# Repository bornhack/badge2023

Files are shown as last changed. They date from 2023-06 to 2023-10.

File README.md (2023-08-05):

# BornHack 2023 NFC Badges

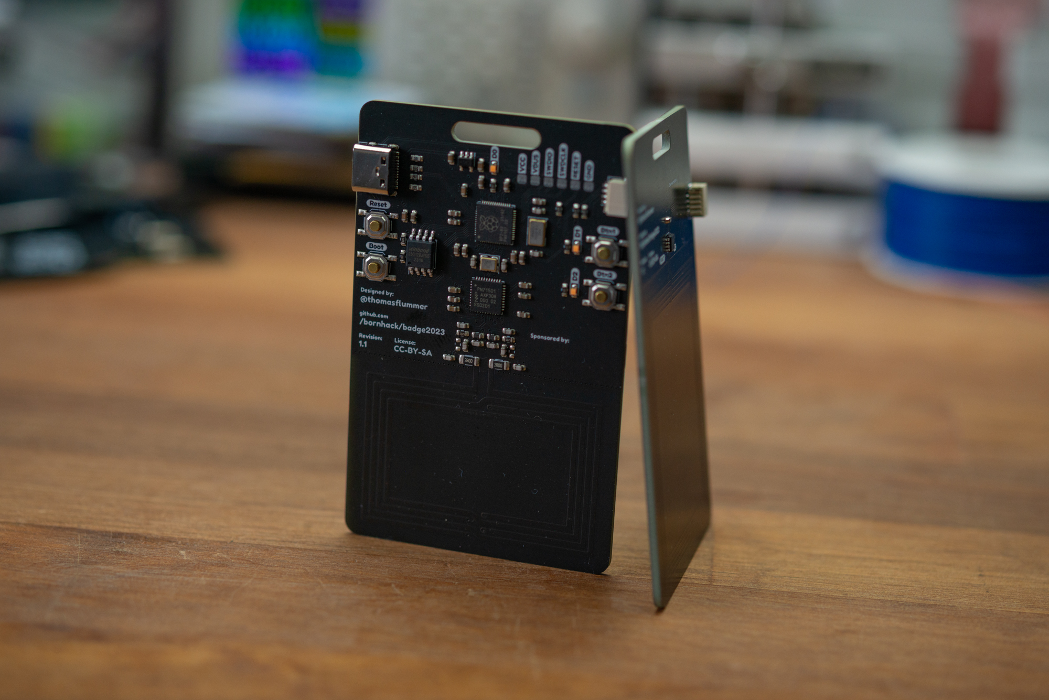
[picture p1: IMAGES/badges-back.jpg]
BornHack 2023 NFC Badges


With this years badges, we are taking a look at NFC. There will be two badges, one that is a tag (using the NXP NTAG I2C Plus chip), and another with an NFC reader (using NXP PN7150), that can also do card emulation.

The reader badge sports an RP2040 dual core Cortex M0+ microcontroller from Raspberry Pi and 16MB of Quad SPI flash for code and data files, to handle USB connection and general application control.

The reader badge will come with [CircuitPython](https://circuitpython.org/) preloaded, for a very low barrier of entry, all you need is a USB-C cable, and your favorite text editor and you're ready for NFC hacking.

## CircuitPython restore file

If you flash the board with something else and want to get back to CircuitPython:
Bring the badge into the UF2 bootloader. This is done by holding the BOOT button and pressing RESET or by holding BOOT while powering on.
The badge will then show up as a mass storage device called something like RP2-?. This is the built in bootloader.
Then simply copy [firmware.uf2](https://github.com/bornhack/badge2023/raw/main/firmware.uf2) from the root of this repository.
The badge will reboot, and you are then back to CircuitPython.

CircuitPython supported with this board is found in the [circuitpython branch](https://github.com/bornhack/badge2023/tree/circuitpython)

The original python files that was on the badge when handed out are in the [cp-init branch](https://github.com/bornhack/badge2023/tree/cp-init)

## Designed in KiCad v7

To open the project, you will need to install a recent release version or one of the nightly builds, KiCad v5 or v6 won't open this design. The [reader schematic as a PDF](https://github.com/bornhack/badge2023/raw/main/nfc_reader/nfc_reader_schematics.pdf) and the [tag schematic as a PDF](https://github.com/bornhack/badge2023/raw/main/nfc_card_emulation_large/nfc_card_emulation_large_schematics.pdf) are included for reference.

Main Components:

- [Raspberry Pi SoC RP2040 - low-cost, high-performance microcontroller device](https://www.raspberrypi.com/documentation/microcontrollers/rp2040.html)
    - [datasheet](https://datasheets.raspberrypi.com/rp2040/rp2040-datasheet.pdf)
    - [RP2040 SDK Manuel](https://www.raspberrypi.com/documentation/microcontrollers/c_sdk.html#sdk-setup)
    - [RP2040 SDK git repository](https://github.com/raspberrypi/pico-sdk)
- [NXP PN7150 - High-Performance NFC Controller with Integrated Firmware](https://www.nxp.com/products/rfid-nfc/nfc-hf/nfc-readers/high-performance-nfc-controller-with-integrated-firmware-for-smart-devices:PN7150)
    - [Datasheet](https://www.nxp.com/docs/en/data-sheet/PN7150.pdf)
    - [User Manual](https://www.nxp.com/docs/en/user-guide/UM10936.pdf)
- [W25Q128JV - 128M-bit Serial Flash Memory with uniform 4KB sectors and Dual/Quad SPI](https://www.winbond.com/hq/product/code-storage-flash-memory/serial-nor-flash/?__locale=en&partNo=W25Q128JV)
    - [datasheet](https://www.winbond.com/hq/support/documentation/downloadV2022.jsp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)
- [NXP NT3H2211W0FTT - NTAG I2C plus 2K, NFC Forum Type 2 Tag with I2C interface](https://www.nxp.com/part/NT3H2211W0FTT#/)
    - [datasheet](https://www.nxp.com/docs/en/data-sheet/NT3H2111_2211.pdf)

## Projects running on the badge

Feel free to submit a PR adding on to this list with your project that runs on the badge.

- _project name and link to more info_

## License

The hardware design of the `main` branch of this repository is released under the following license:

* the "Creative Commons Attribution-ShareAlike 4.0 International License"
  (CC BY-SA 4.0) full text of this license is included in the LICENSE file
  and a copy can also be found at
  [http://creativecommons.org/licenses/by-sa/4.0/](http://creativecommons.org/licenses/by-sa/4.0/)

The CircuitPython firmware of the `circuitpython` branch is released under the MIT license with smaller dependencies under other licenses as detailed in [its LICENSE](https://github.com/bornhack/badge2023/blob/circuitpython/LICENSE) and [LICENSE_MicroPython](https://github.com/bornhack/badge2023/blob/circuitpython/LICENSE_MicroPython) files.

The Python NFC demonstration application of the `cp-init` branch is released under the MIT license as detailed in its [LICENSE file](https://github.com/bornhack/badge2023/blob/cp-init/LICENSE).

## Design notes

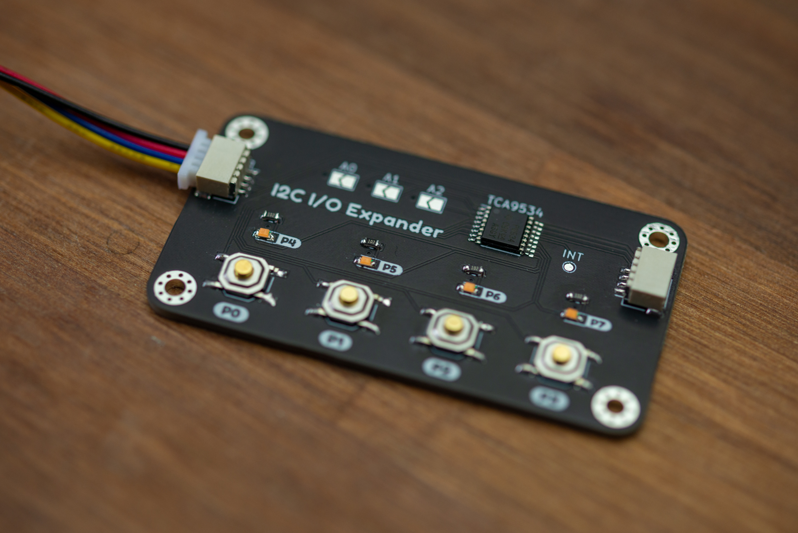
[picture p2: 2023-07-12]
IMAGES/io-expander.jpg

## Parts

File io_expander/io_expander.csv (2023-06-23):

Id | Designator | Footprint | Quantity | Designation | Supplier and ref
1 | R2,R4,R1,R3 | R_0603_1608Metric | 4 | 1k
2 | SW3,SW2,SW1,SW4 | SW_SPST_TL3342 | 4 | TS5220A
3 | J1,J2 | JST_SH_SM04B-SRSS-TB_1x04-1MP_P1.00mm_Horizontal | 2 | LCSC C145956
4 | D1,D4,D2,D3 | LED_0603_1608Metric | 4 | LED
5 | U1 | TSSOP-16_4.4x5mm_P0.65mm | 1 | TCA9534

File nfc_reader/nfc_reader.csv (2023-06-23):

Id | Designator | Footprint | Quantity | Designation | Supplier and ref
1 | R2,R1,R11,R10 | R_0603_1608Metric | 4 | 10k
2 | Y2 | Crystal_SMD_3225-4Pin_3.2x2.5mm | 1 | 27.12MHz, 10pF
3 | L2,L1 | L_0603_1608Metric | 2 | 560nH, 5%
4 | C10,C8,C14,C11,C9,C19,C13,C18,C6,C7,C4 | C_0603_1608Metric | 11 | 100nF
5 | SW2,SW7,SW6,SW1 | SW_SPST_TL3342 | 4 | TS5220A
6 | C27,C28,C29,C30 | C_0603_1608Metric | 4 | 200pF/16V, NP0, 5%
7 | C12,C5,C17 | C_0603_1608Metric | 3 | 2.2uF
8 | C23,C24 | C_0603_1608Metric | 2 | 10pF
9 | R3,R9,R4,R12,R17,R18 | R_0603_1608Metric | 6 | 1k
10 | R15,R16 | R_1206_3216Metric | 2 | 2.00R 1%
11 | C3,C2,C22,C1,C20 | C_0603_1608Metric | 5 | 1uF
12 | Y1 | Crystal_SMD_5032-4Pin_5.0x3.2mm | 1 | 12MHz, 20pF
13 | J2 | JST_SH_SM04B-SRSS-TB_1x04-1MP_P1.00mm_Horizontal | 1 | LCSC C145956
14 | R7,R8 | R_0603_1608Metric | 2 | 5.1k
15 | C31,C32 | C_0603_1608Metric | 2 | 27pF/50V, NP0, 2%
16 | C25,C26 | C_0603_1608Metric | 2 | 1nF/16V
17 | J1 | USB_C_Receptacle_XKB_U262-16XN-4BVC11 | 1 | USB_C
18 | R14,R13 | R_0603_1608Metric | 2 | 27R
19 | D0,D1,D2 | LED_0603_1608Metric | 3 | LED
20 | C16,C15 | C_0603_1608Metric | 2 | 30pF
21 | C21 | C_0603_1608Metric | 1 | 4.7uF
22 | U5 | QFN-56_EP_7x7_Pitch0.4mm | 1 | RP2040
23 | U1 | SOT-23-5 | 1 | HX9193-33GB
24 | U3 | HVQFN-40-1EP_6x6mm_P0.5mm_EP4.1x4.1mm | 1 | PN7150B0HN/C11002Y
25 | U4 | SOIC-8_5.23x5.23mm_P1.27mm | 1 | W25QXX128MBIT

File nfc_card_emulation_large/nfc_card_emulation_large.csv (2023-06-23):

Id | Designator | Footprint | Quantity | Designation | Supplier and ref
1 | J3 | JST_SH_SM04B-SRSS-TB_1x04-1MP_P1.00mm_Horizontal | 1 | LCSC C145956
2 | C33 | C_0603_1608Metric | 1 | 100nf
3 | U2 | TSSOP-8_3x3mm_P0.65mm | 1 | NT3H2211

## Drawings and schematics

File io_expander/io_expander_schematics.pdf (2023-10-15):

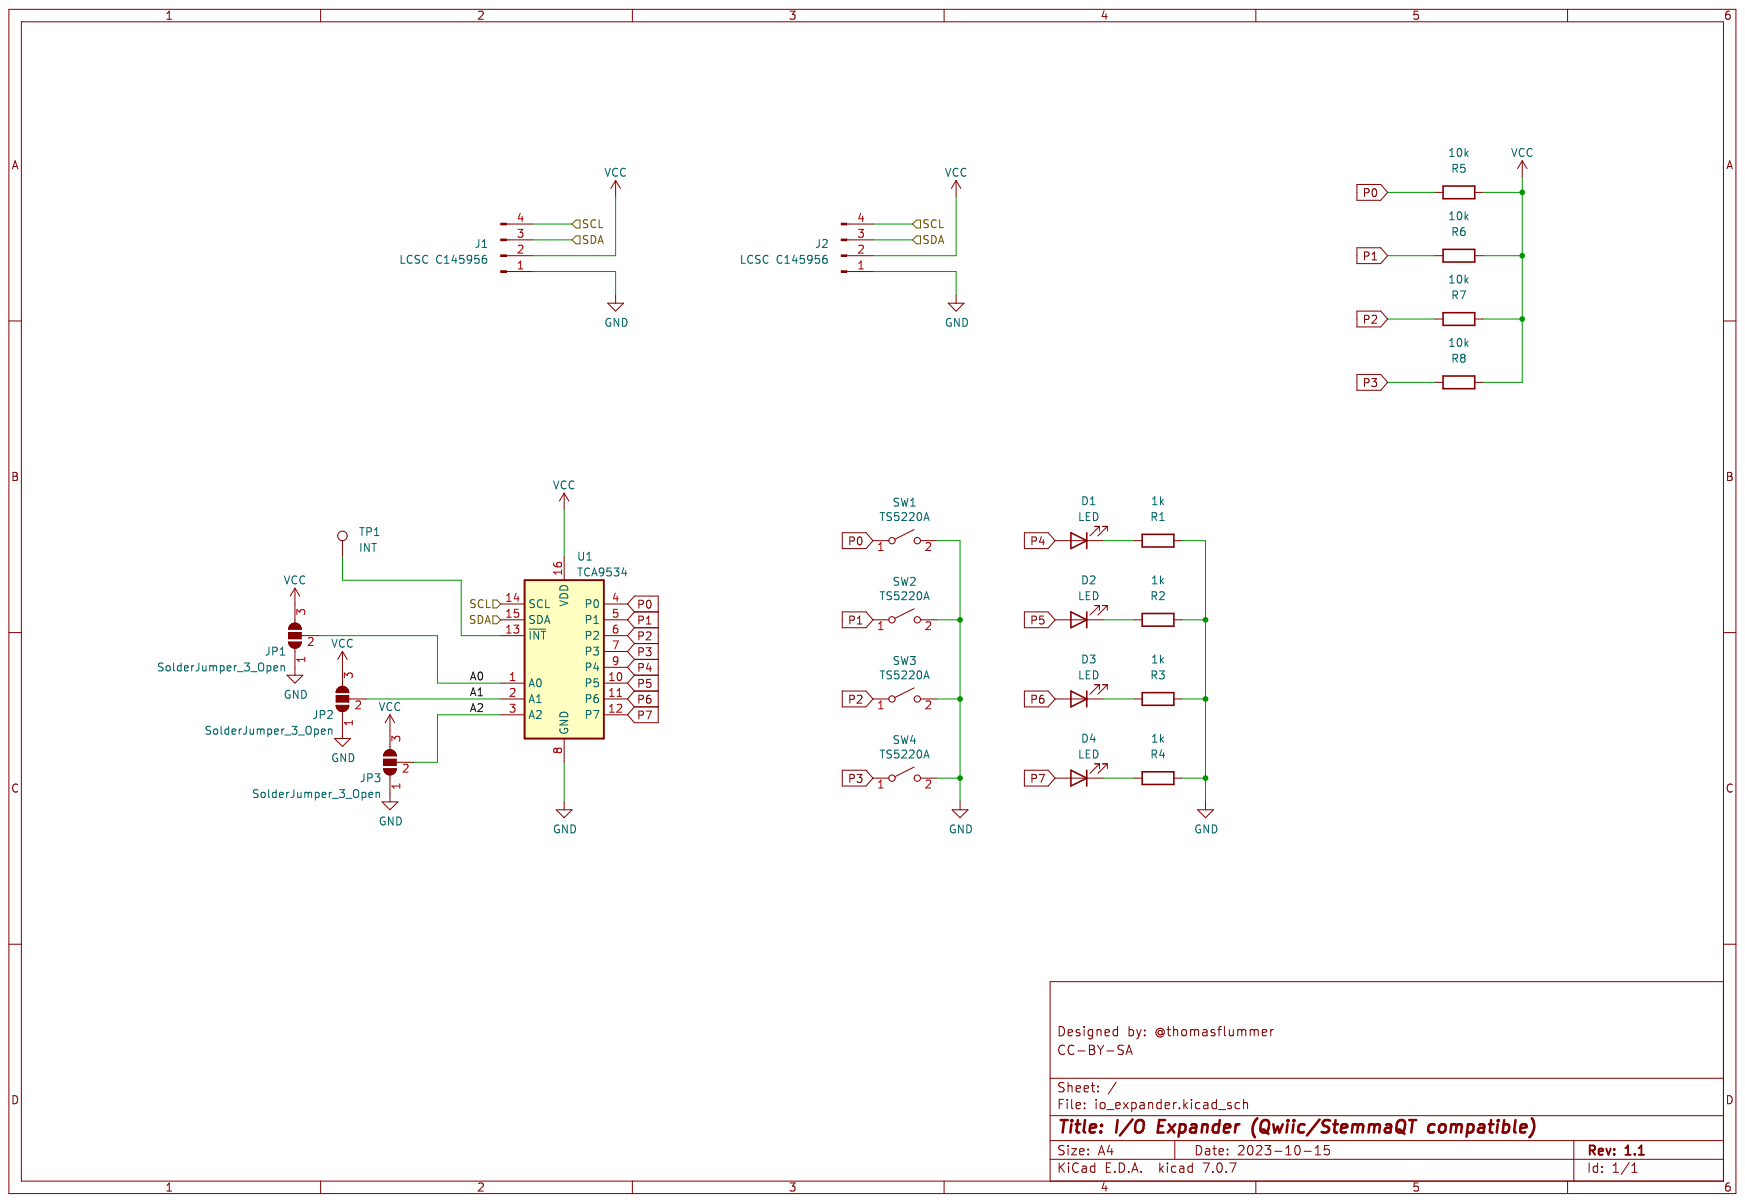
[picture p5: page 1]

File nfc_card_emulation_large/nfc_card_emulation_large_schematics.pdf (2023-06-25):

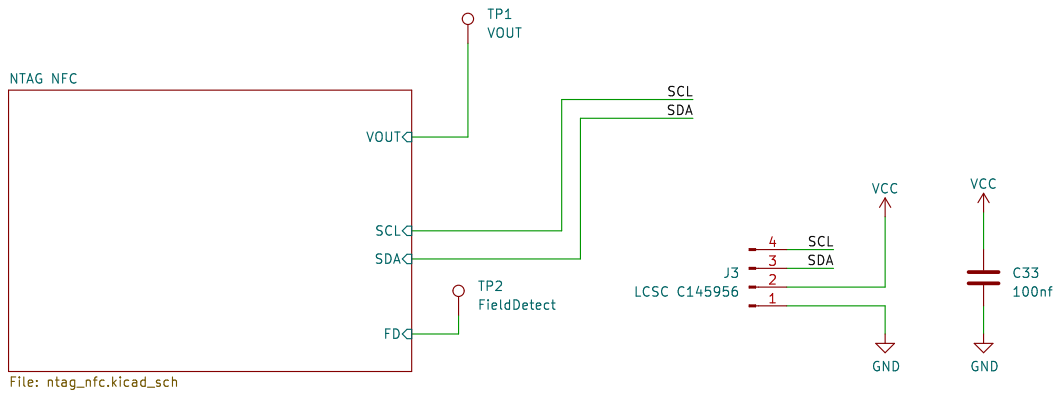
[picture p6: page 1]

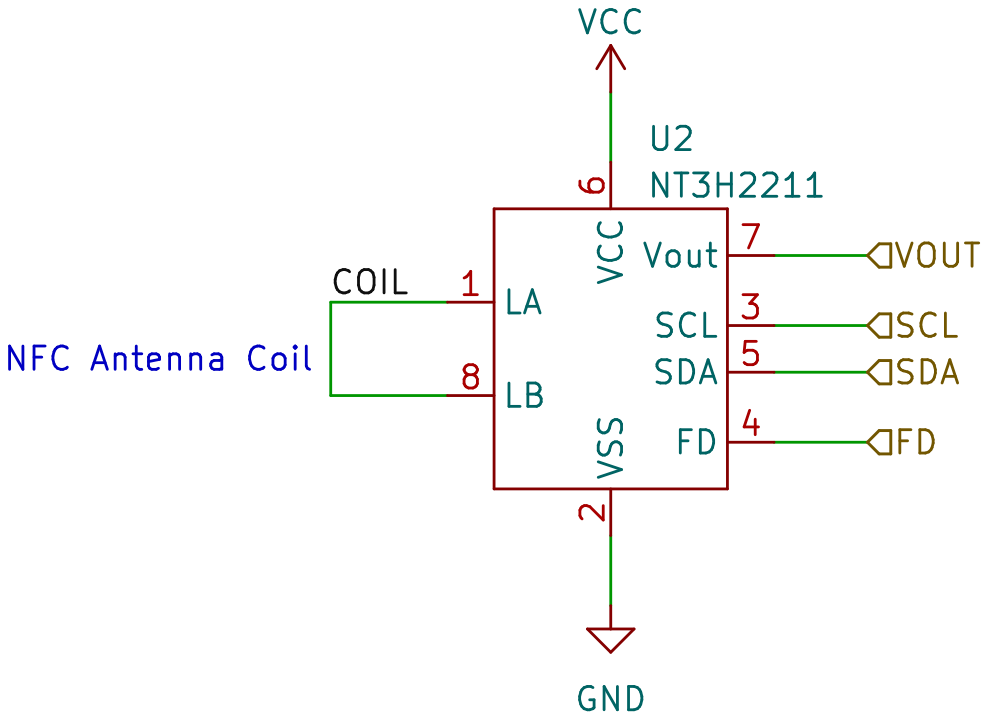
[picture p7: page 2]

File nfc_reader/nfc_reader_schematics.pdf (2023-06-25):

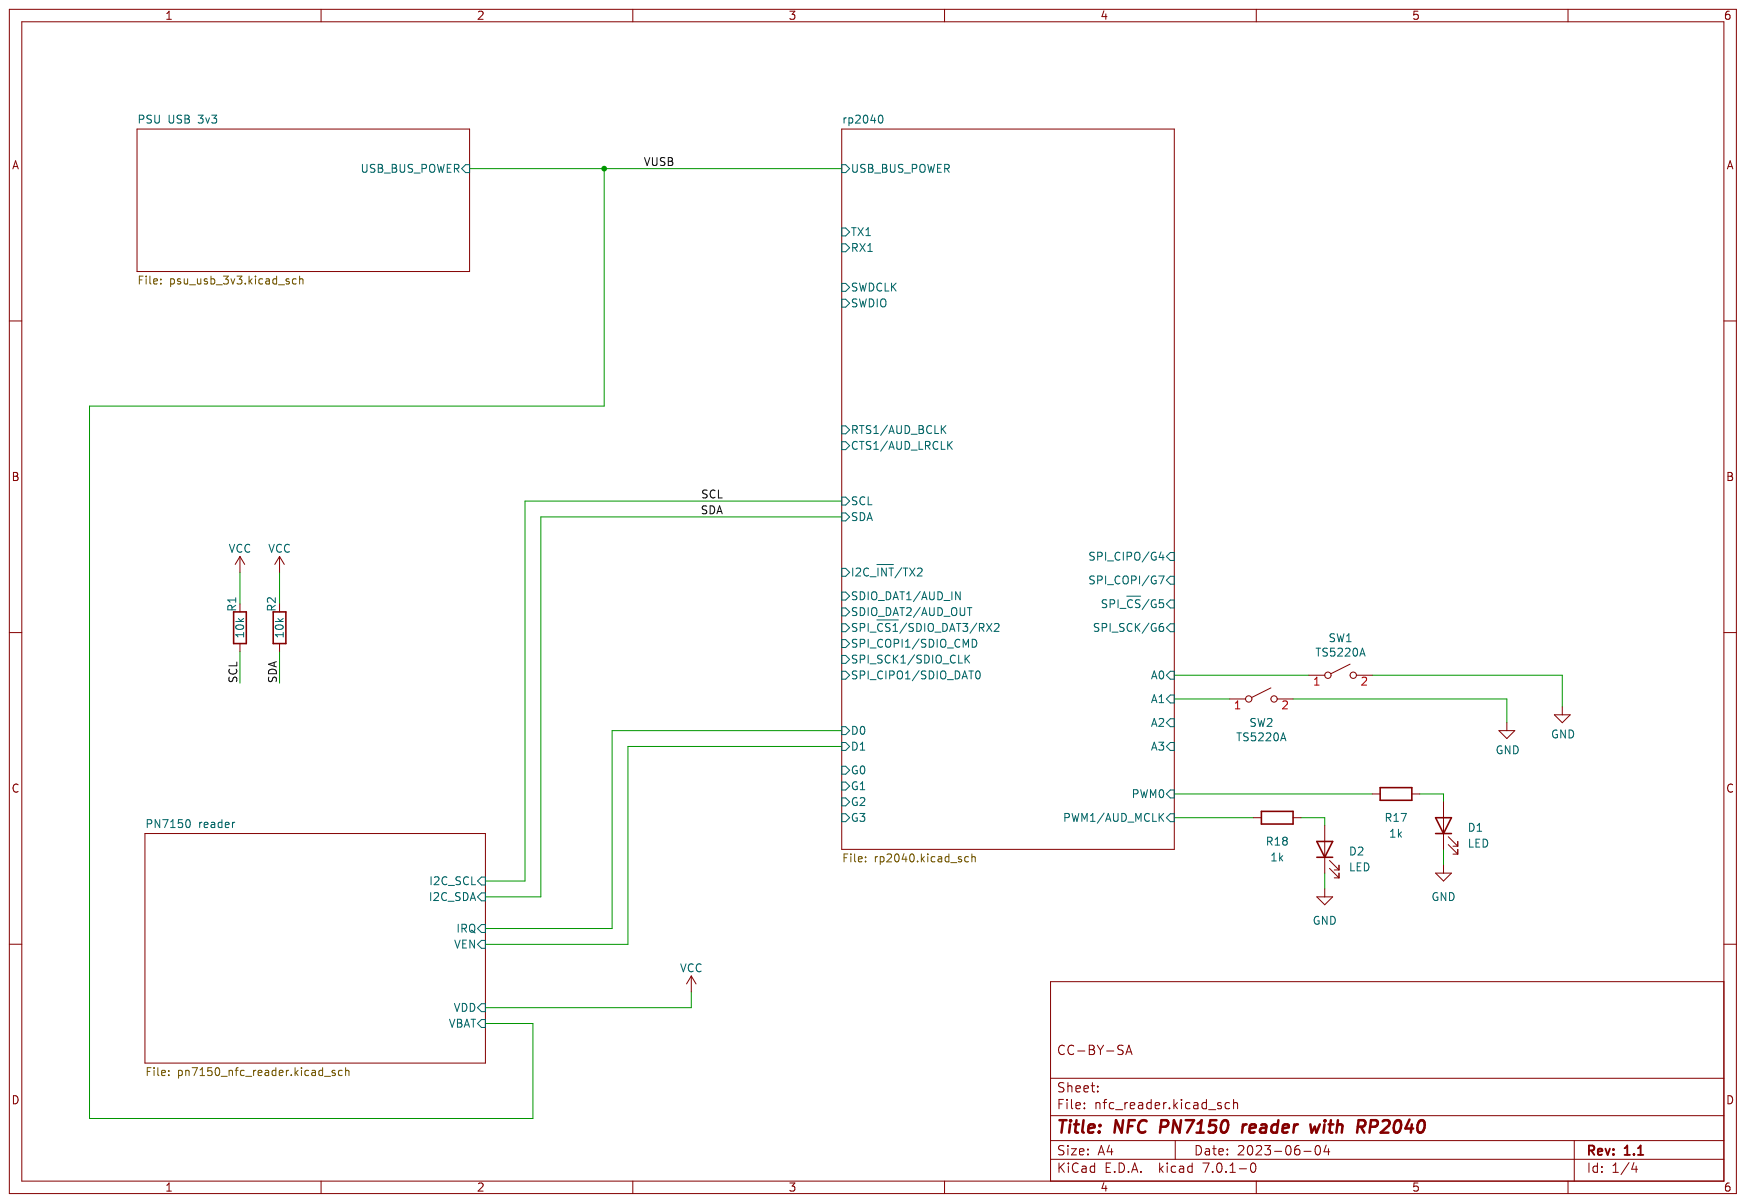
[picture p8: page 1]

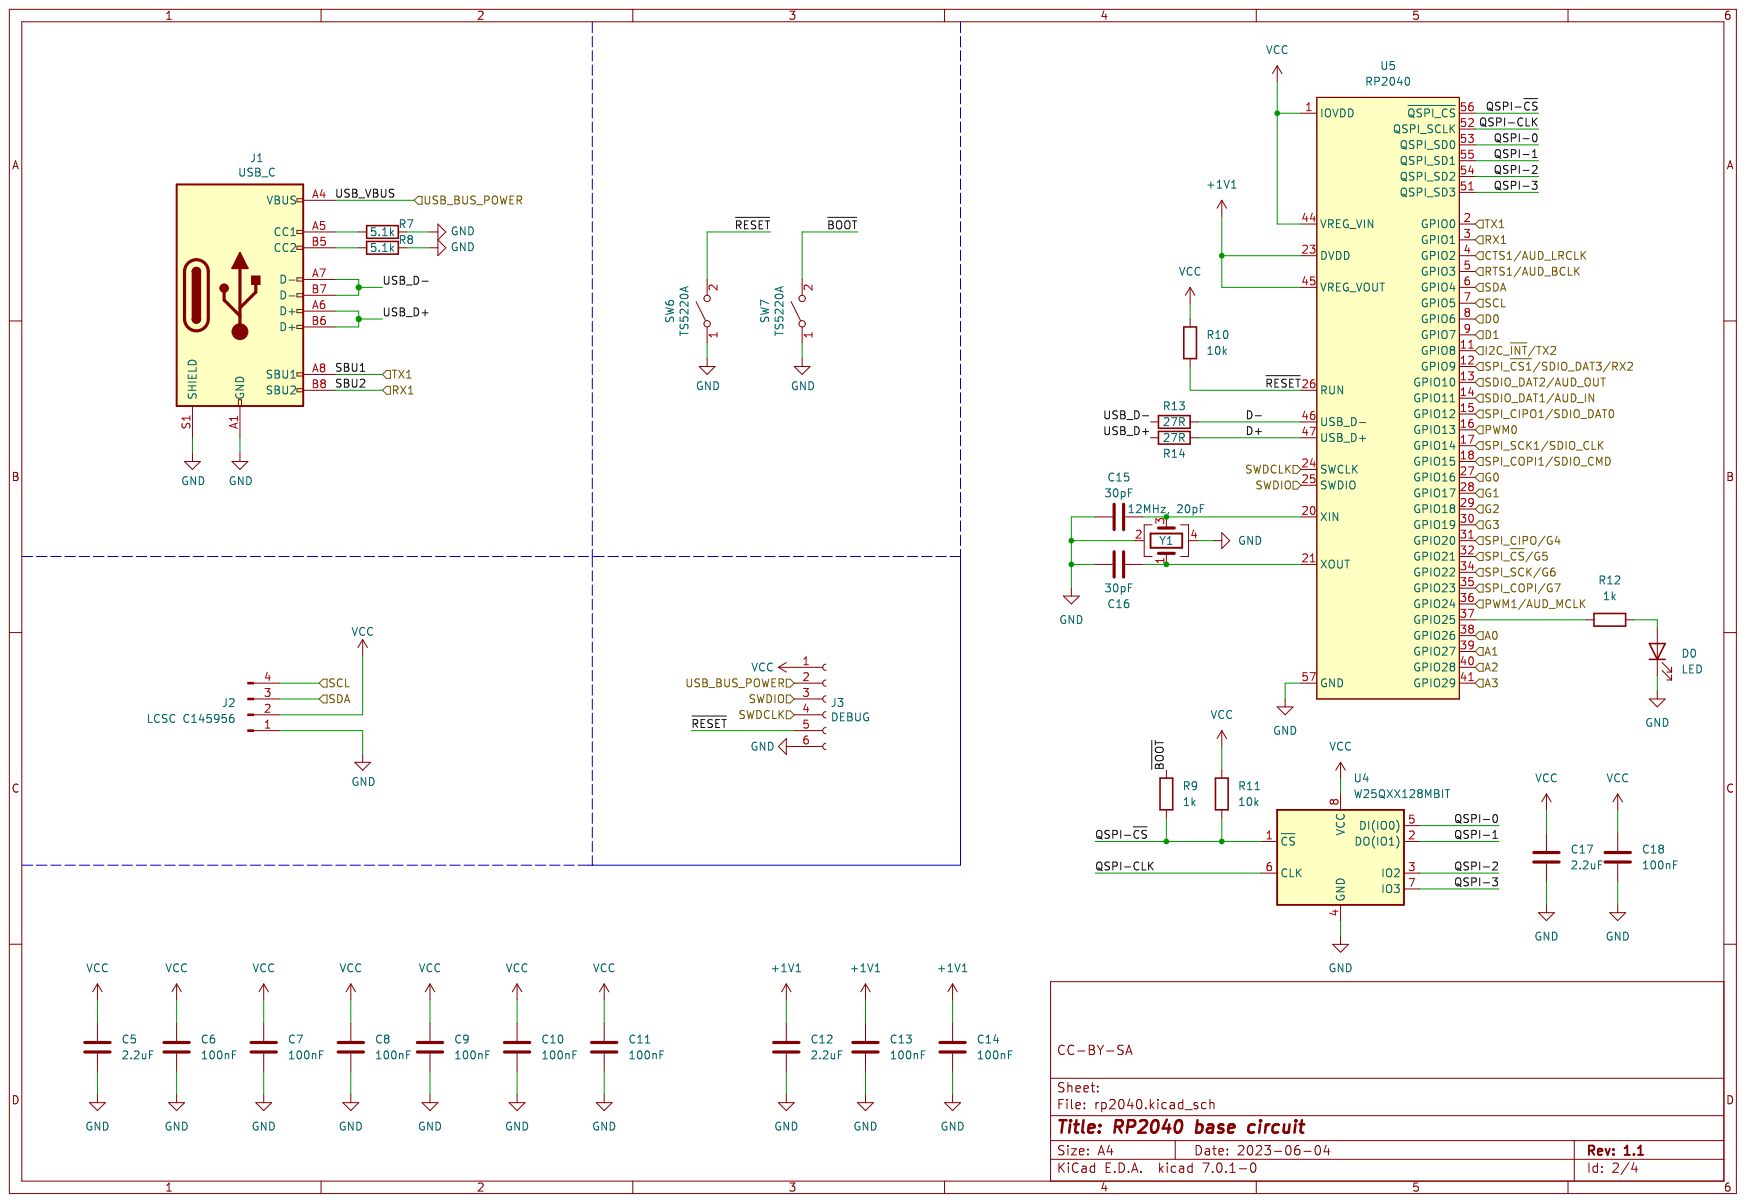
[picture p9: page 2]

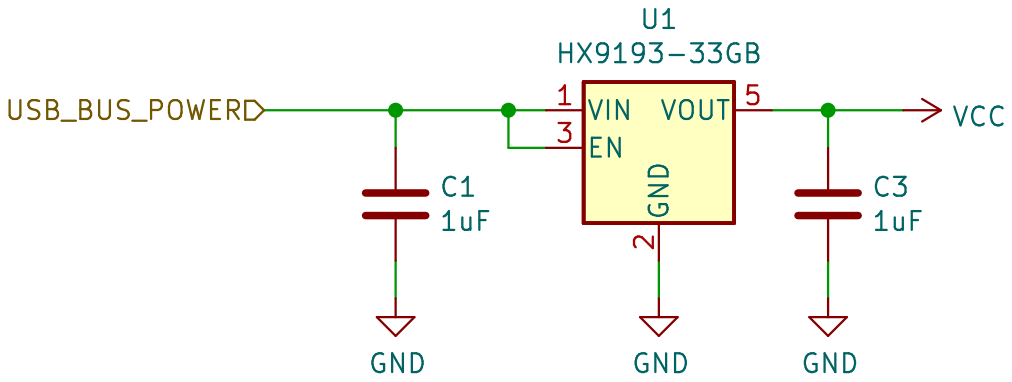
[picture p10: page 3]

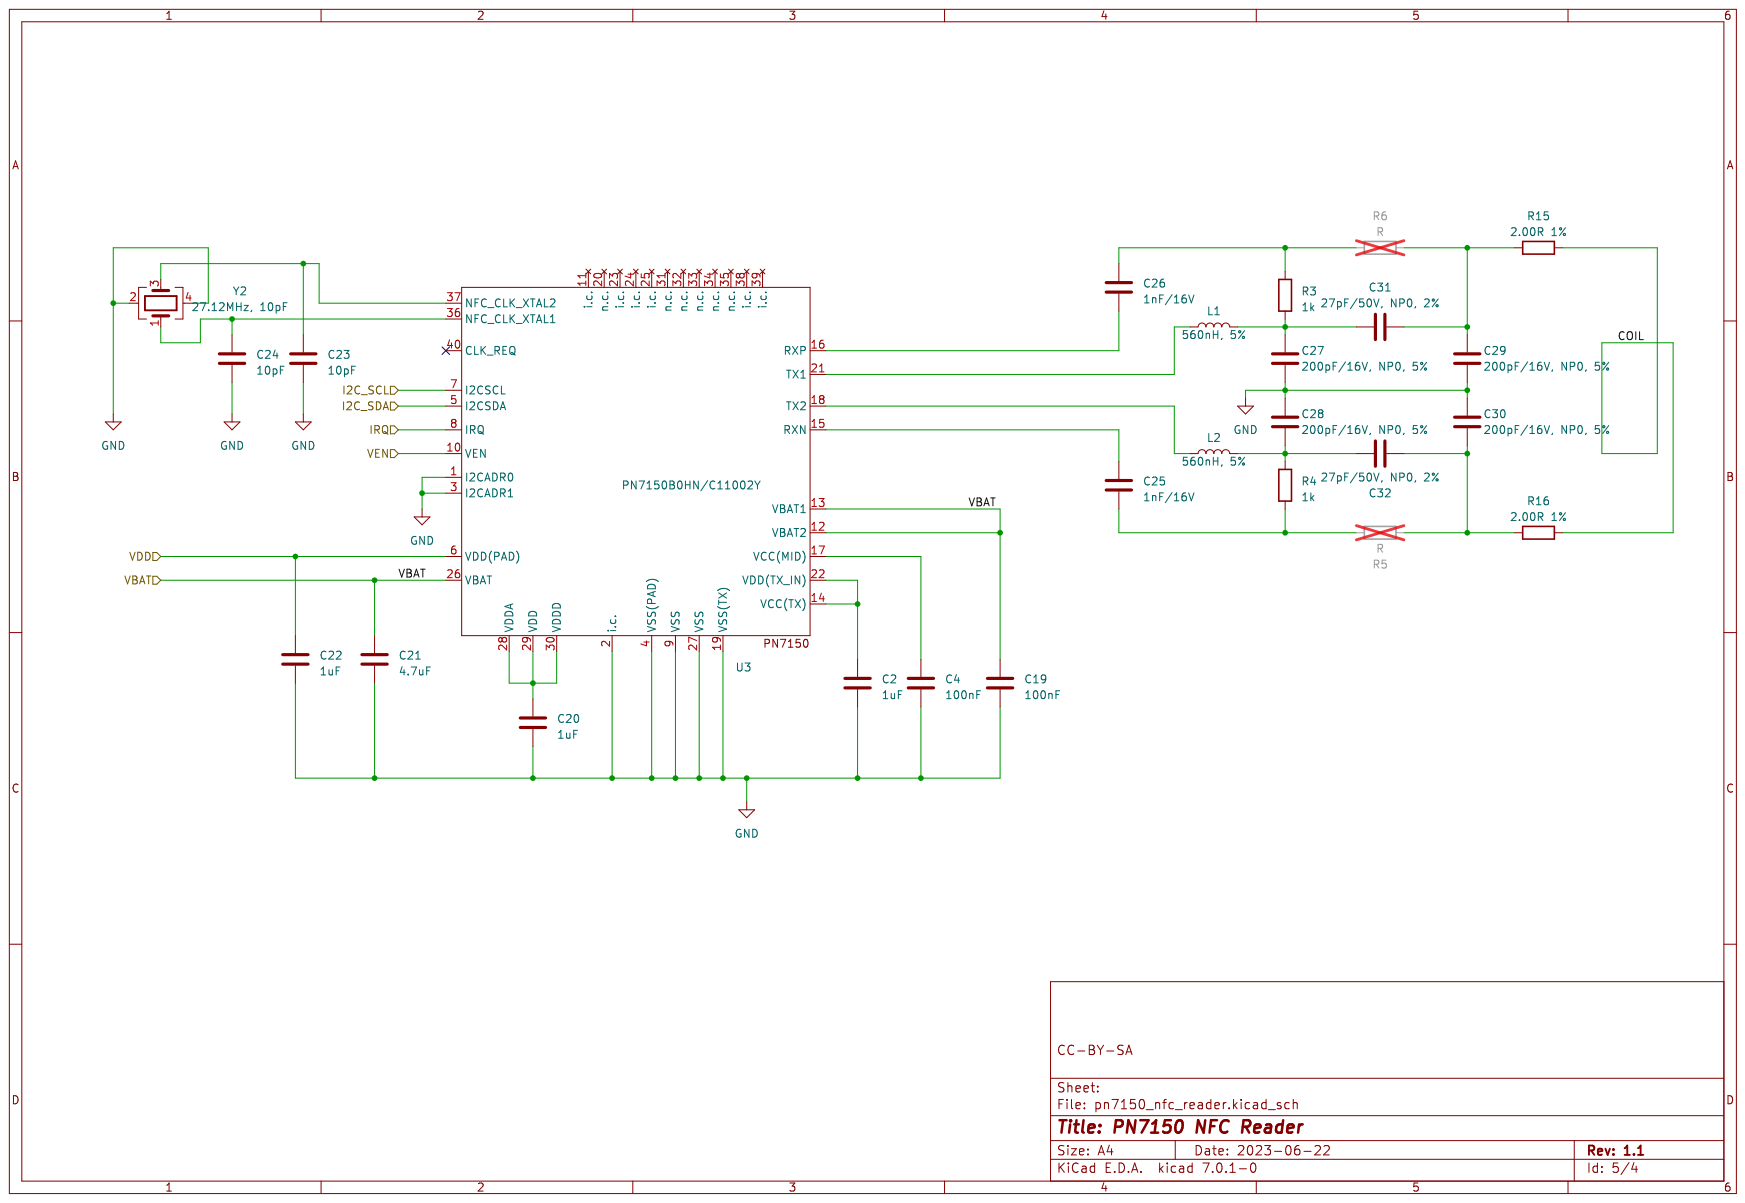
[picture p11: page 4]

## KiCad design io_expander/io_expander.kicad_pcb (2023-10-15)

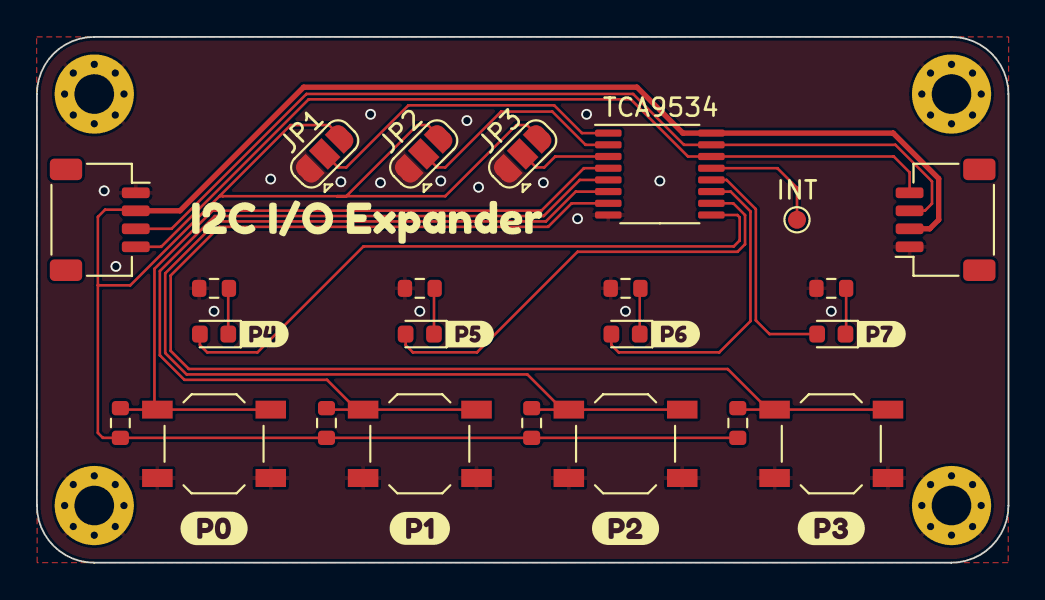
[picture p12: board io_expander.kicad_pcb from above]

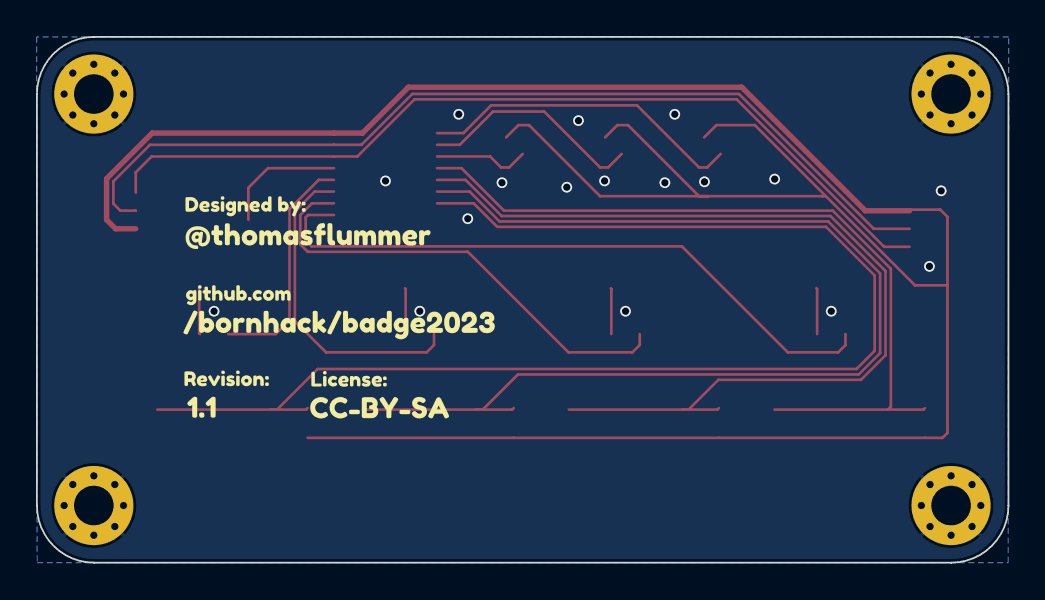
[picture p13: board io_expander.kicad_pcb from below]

Board: 2 copper layers, 54.0 x 29.2 mm, 40 parts (8 on the bottom side), 20 nets.

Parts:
D1, D2, D3, D4: LED; LED_0603_1608Metric
J1, J2: LCSC C145956; JST_SH_SM04B-SRSS-TB_1x04-1MP_P1.00mm_Horizontal
JP1, JP2, JP3: SolderJumper_3_Open; SolderJumper-3_P1.3mm_Open_RoundedPad1.0x1.5mm
R1, R2, R3, R4: 1k; R_0603_1608Metric
R5, R6, R7, R8: 10k; R_0603_1608Metric
SW1, SW2, SW3, SW4: TS5220A; SW_SPST_TL3342
TP1: INT; TestPoint_Pad_D1.0mm
U1: TCA9534; TSSOP-16_4.4x5mm_P0.65mm
kibuzzard-645C11AA: G***; kibuzzard-645C11AA
kibuzzard-645C104C: G***; kibuzzard-645C104C
kibuzzard-645C107E: G***; kibuzzard-645C107E
kibuzzard-645C118B: G***; kibuzzard-645C118B
kibuzzard-645C1150: G***; kibuzzard-645C1150
kibuzzard-652C0514: G***; kibuzzard-652C0514
kibuzzard-6495A71A: G***; kibuzzard-6495A71A
kibuzzard-6495A79F: G***; kibuzzard-6495A79F
kibuzzard-6495A738: G***; kibuzzard-6495A738
kibuzzard-6495A742: G***; kibuzzard-6495A742
kibuzzard-6495A748: G***; kibuzzard-6495A748
kibuzzard-6495A762: G***; kibuzzard-6495A762
kibuzzard-6495A791: G***; kibuzzard-6495A791
kibuzzard-6495A798: G***; kibuzzard-6495A798
kibuzzard-6495A825: G***; kibuzzard-6495A825
kibuzzard-64946969: G***; kibuzzard-64946969
kibuzzard-64946977: G***; kibuzzard-64946977

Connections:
/A0: JP1.2 (C), U1.1 (A0)
/A1: JP2.2 (C), U1.2 (A1)
/A2: JP3.2 (C), U1.3 (A2)
/SCL: J1.4, J2.4, U1.14 (SCL)
/SDA: J1.3, J2.3, U1.15 (SDA)
GND: J1.1, J2.1, JP1.1 (A), JP2.1 (A), JP3.1 (A), R1.2, R2.2, R3.2, R4.2, SW1.2 (B), SW2.2 (B), SW3.2 (B), SW4.2 (B), U1.8 (GND)
unnamed: D1.1 (K), R1.1
unnamed: D2.1 (K), R2.1
unnamed: D3.1 (K), R3.1
unnamed: D4.1 (K), R4.1
unnamed: TP1.1, U1.13 (~INT)
P0: R5.1, SW1.1 (A), U1.4 (P0)
P1: R6.1, SW2.1 (A), U1.5 (P1)
P2: R7.1, SW3.1 (A), U1.6 (P2)
P3: R8.1, SW4.1 (A), U1.7 (P3)
P4: D1.2 (A), U1.9 (P4)
P5: D2.2 (A), U1.10 (P5)
P6: D3.2 (A), U1.11 (P6)
P7: D4.2 (A), U1.12 (P7)
VCC: J1.2, J2.2, JP1.3 (B), JP2.3 (B), JP3.3 (B), R5.2, R6.2, R7.2, R8.2, U1.16 (VDD)

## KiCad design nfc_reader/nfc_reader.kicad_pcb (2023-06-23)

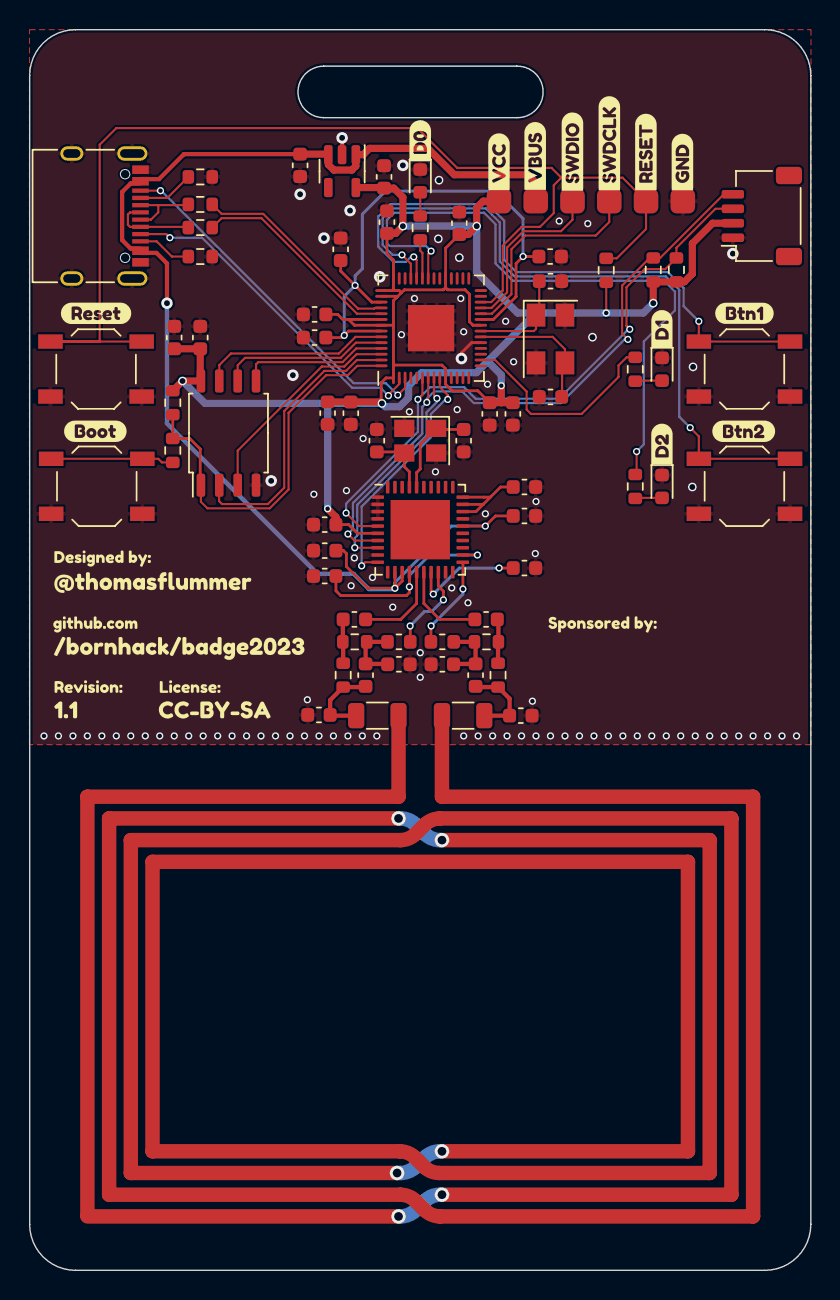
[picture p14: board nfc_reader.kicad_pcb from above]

Board: 2 copper layers, 54.0 x 85.7 mm, 90 parts (0 on the bottom side), 52 nets.

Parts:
C1, C2, C3, C20, C22: 1uF; C_0603_1608Metric
C4, C6, C7, C8, C9, C10, C11, C13, C14, C18, C19: 100nF; C_0603_1608Metric
C5, C12, C17: 2.2uF; C_0603_1608Metric
C15, C16: 30pF; C_0603_1608Metric
C21: 4.7uF; C_0603_1608Metric
C23, C24: 10pF; C_0603_1608Metric
C25, C26: 1nF/16V; C_0603_1608Metric
C27, C28, C29, C30: 200pF/16V, NP0, 5%; C_0603_1608Metric
C31, C32: 27pF/50V, NP0, 2%; C_0603_1608Metric
D0, D1, D2: LED; LED_0603_1608Metric
J1: USB_C; USB_C_Receptacle_XKB_U262-16XN-4BVC11
J2: LCSC C145956; JST_SH_SM04B-SRSS-TB_1x04-1MP_P1.00mm_Horizontal
J3: DEBUG; PinHeader_1x06_P2.54mm_Vertical
L1, L2: 560nH, 5%; L_0603_1608Metric
R1, R2, R10, R11: 10k; R_0603_1608Metric
R3, R4, R9, R12, R17, R18: 1k; R_0603_1608Metric
R5, R6: R; R_0603_1608Metric
R7, R8: 5.1k; R_0603_1608Metric
R13, R14: 27R; R_0603_1608Metric
R15, R16: 2.00R 1%; R_1206_3216Metric
SW1, SW2, SW6, SW7: TS5220A; SW_SPST_TL3342
U1: HX9193-33GB; SOT-23-5
U3: PN7150B0HN/C11002Y; HVQFN-40-1EP_6x6mm_P0.5mm_EP4.1x4.1mm
U4: W25QXX128MBIT; SOIC-8_5.23x5.23mm_P1.27mm
U5: RP2040; QFN-56_EP_7x7_Pitch0.4mm
Y1: 12MHz, 20pF; Crystal_SMD_5032-4Pin_5.0x3.2mm
Y2: 27.12MHz, 10pF; Crystal_SMD_3225-4Pin_3.2x2.5mm
kibuzzard-645C11AA: G***; kibuzzard-645C11AA
kibuzzard-645C104C: G***; kibuzzard-645C104C
kibuzzard-645C107E: G***; kibuzzard-645C107E
kibuzzard-645C118B: G***; kibuzzard-645C118B
kibuzzard-645C1150: G***; kibuzzard-645C1150
kibuzzard-647C7A14: G***; kibuzzard-647C7A14
kibuzzard-647C89AC: G***; kibuzzard-647C89AC
kibuzzard-647C89B2: G***; kibuzzard-647C89B2
kibuzzard-647C8669: G***; kibuzzard-647C8669
kibuzzard-647C8670: G***; kibuzzard-647C8670
kibuzzard-647C8676: G***; kibuzzard-647C8676
kibuzzard-6457AB78: G***; kibuzzard-6457AB78
kibuzzard-6457ABA7: G***; kibuzzard-6457ABA7
kibuzzard-6457ABCE: G***; kibuzzard-6457ABCE
kibuzzard-6457ABE9: G***; kibuzzard-6457ABE9
kibuzzard-6457ABF7: G***; kibuzzard-6457ABF7
kibuzzard-6457AC2E: G***; kibuzzard-6457AC2E
kibuzzard-6457AC15: G***; kibuzzard-6457AC15
kibuzzard-6457AC22: G***; kibuzzard-6457AC22
kibuzzard-64945DE3: G***; kibuzzard-64945DE3
kibuzzard-64945DF1: G***; kibuzzard-64945DF1
kibuzzard-64946152: G***; kibuzzard-64946152

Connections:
+1V1: C12.1, C13.1, C14.1, U5.23 (DVDD), U5.45 (VREG_VOUT), U5.50 (DVDD)
/PN7150 reader/COIL: R15.2, R16.2
/PN7150 reader/IRQ: U3.8 (IRQ), U5.8 (GPIO6)
/PN7150 reader/VEN: U3.10 (VEN), U5.9 (GPIO7)
/SCL: J2.4, R1.2, U3.7 (I2CSCL), U5.7 (GPIO5)
/SDA: J2.3, R2.2, U3.5 (I2CSDA), U5.6 (GPIO4)
/VUSB: C1.1, C19.1, C21.1, J1.A4 (VBUS), J1.A9 (VBUS), J1.B4 (VBUS), J1.B9 (VBUS), J3.2, U1.1 (VIN), U1.3 (EN), U3.12 (VBAT2), U3.13 (VBAT1), U3.26 (VBAT)
/rp2040/A0: SW1.1 (A), U5.38 (GPIO26)
/rp2040/A1: SW2.1 (A), U5.39 (GPIO27)
/rp2040/D+: R14.2, U5.47 (USB_D+)
/rp2040/D-: R13.2, U5.46 (USB_D-)
/rp2040/PWM0: R17.2, U5.16 (GPIO13)
/rp2040/PWM1/AUD_MCLK: R18.2, U5.36 (GPIO24)
/rp2040/QSPI-0: U4.5 (DI(IO0)), U5.53 (QSPI_SD0)
/rp2040/QSPI-1: U4.2 (DO(IO1)), U5.55 (QSPI_SD1)
/rp2040/QSPI-2: U4.3 (IO2), U5.54 (QSPI_SD2)
/rp2040/QSPI-3: U4.7 (IO3), U5.51 (QSPI_SD3)
/rp2040/QSPI-CLK: U4.6 (CLK), U5.52 (QSPI_SCLK)
/rp2040/QSPI-~CS: R9.2, R11.2, U4.1 (~CS), U5.56 (~QSPI_CS)
/rp2040/SBU1: J1.A8 (SBU1), U5.2 (GPIO0)
/rp2040/SBU2: J1.B8 (SBU2), U5.3 (GPIO1)
/rp2040/SWDCLK: J3.4, U5.24 (SWCLK)
/rp2040/SWDIO: J3.3, U5.25 (SWDIO)
/rp2040/USB_D+: J1.A6 (D+), J1.B6 (D+), R14.1
/rp2040/USB_D-: J1.A7 (D-), J1.B7 (D-), R13.1
/rp2040/~BOOT: R9.1, SW7.2 (B)
/rp2040/~RESET: J3.5, R10.2, SW6.2 (B), U5.26 (RUN)
GND: C1.2, C2.2, C3.2, C4.2, C5.2, C6.2, C7.2, C8.2, C9.2, C10.2, C11.2, C12.2, C13.2, C14.2, C15.1, C16.1, C17.2, C18.2, C19.2, C20.2, C21.2, C22.2, C23.2, C24.2, C27.2, C28.1, C29.2, C30.1, D0.1 (K), D1.1 (K), D2.1 (K), J1.A1 (GND), J1.A12 (GND), J1.B1 (GND), J1.B12 (GND), J1.S1 (SHIELD), J2.1, J3.6, R7.1, R8.1, SW1.2 (B), SW2.2 (B), SW6.1 (A), SW7.1 (A), U1.2 (GND), U3.1 (I2CADR0), U3.2 (i.c.), U3.3 (I2CADR1), U3.4 (VSS(PAD)), U3.9 (VSS), U3.19 (VSS(TX)), U3.27 (VSS), U4.4 (GND), U5.19 (TESTEN), U5.57 (GND), Y1.2, Y1.4, Y2.2, Y2.4
unnamed: C25.2, R4.2, R5.1
unnamed: C26.1, R3.1, R6.1
unnamed: C27.1, C31.1, L1.2, R3.2
unnamed: C28.2, C32.1, L2.2, R4.1
unnamed: C29.1, C31.2, R6.2, R15.1
unnamed: C30.2, C32.2, R5.2, R16.1
unnamed: D0.2 (A), R12.1
unnamed: D1.2 (A), R17.1
unnamed: D2.2 (A), R18.1
unnamed: J1.A5 (CC1), R7.2
unnamed: J1.B5 (CC2), R8.2
unnamed: C24.1, U3.36 (NFC_CLK_XTAL1), Y2.1
unnamed: C23.1, U3.37 (NFC_CLK_XTAL2), Y2.3
unnamed: C25.1, U3.15 (RXN)
unnamed: C26.2, U3.16 (RXP)
unnamed: L1.1, U3.21 (TX1)
unnamed: L2.1, U3.18 (TX2)
unnamed: C4.1, U3.17 (VCC(MID))
unnamed: C2.1, U3.14 (VCC(TX)), U3.22 (VDD(TX_IN))
unnamed: C20.1, U3.28 (VDDA), U3.29 (VDD), U3.30 (VDDD)
unnamed: R12.2, U5.37 (GPIO25)
unnamed: C15.2, U5.20 (XIN), Y1.3
unnamed: C16.2, U5.21 (XOUT), Y1.1
VCC: C3.1, C5.1, C6.1, C7.1, C8.1, C9.1, C10.1, C11.1, C17.1, C18.1, C22.1, J2.2, J3.1, R1.1, R2.1, R10.1, R11.1, U1.5 (VOUT), U3.6 (VDD(PAD)), U4.8 (VCC), U5.1 (IOVDD), U5.10 (IOVDD), U5.22 (IOVDD), U5.33 (IOVDD), U5.42 (IOVDD), U5.43 (ADC_AVDD), U5.44 (VREG_VIN), U5.48 (USB_VDD), U5.49 (IOVDD)

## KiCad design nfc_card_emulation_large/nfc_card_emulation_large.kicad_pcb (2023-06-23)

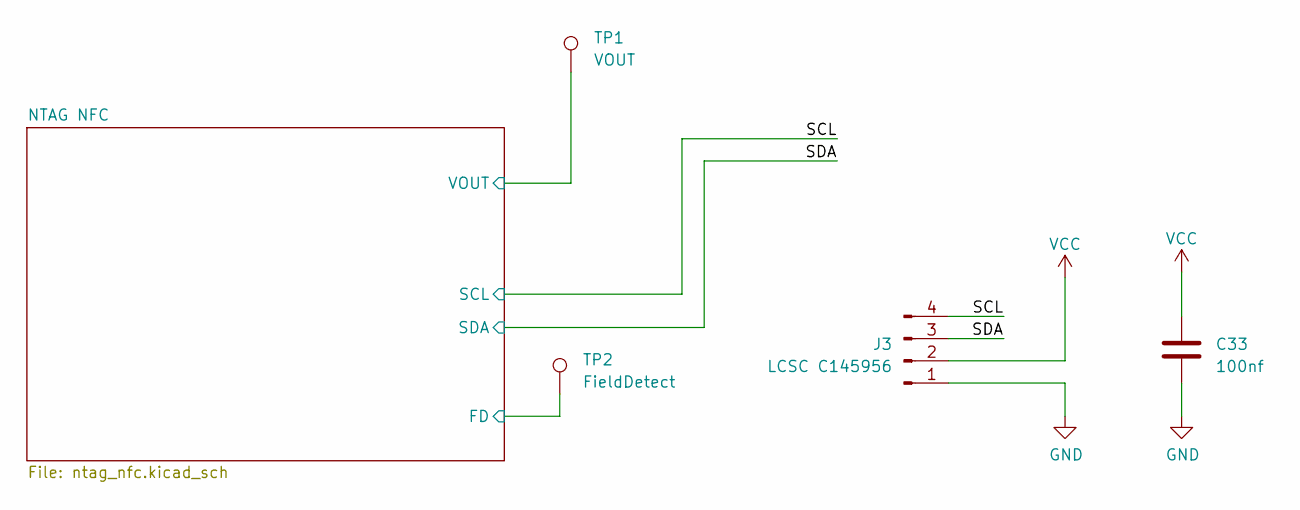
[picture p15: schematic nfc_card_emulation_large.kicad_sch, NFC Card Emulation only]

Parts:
C33: 100nf; C_0603_1608Metric
J3: LCSC C145956; JST_SH_SM04B-SRSS-TB_1x04-1MP_P1.00mm_Horizontal
TP1: VOUT; TestPoint_Pad_D1.0mm
TP2: FieldDetect; TestPoint_Pad_D1.0mm

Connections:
/NTAG NFC/FD: TP2.1; also elsewhere on the board
/NTAG NFC/VOUT: TP1.1; also elsewhere on the board
/SCL: J3.4; also elsewhere on the board
/SDA: J3.3; also elsewhere on the board
GND: C33.2, J3.1; also elsewhere on the board
VCC: C33.1, J3.2; also elsewhere on the board

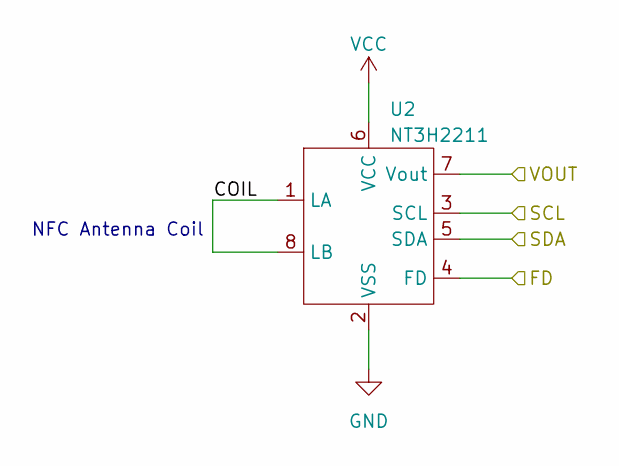
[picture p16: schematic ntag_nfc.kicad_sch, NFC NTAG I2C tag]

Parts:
U2: NT3H2211; TSSOP-8_3x3mm_P0.65mm

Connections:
/NTAG NFC/COIL: U2.1 (LA), U2.8 (LB)
/NTAG NFC/FD: U2.4 (FD); also elsewhere on the board
/NTAG NFC/VOUT: U2.7 (Vout); also elsewhere on the board
/SCL: U2.3 (SCL); also elsewhere on the board
/SDA: U2.5 (SDA); also elsewhere on the board
GND: U2.2 (VSS); also elsewhere on the board
VCC: U2.6 (VCC); also elsewhere on the board

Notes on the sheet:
NFC Antenna Coil

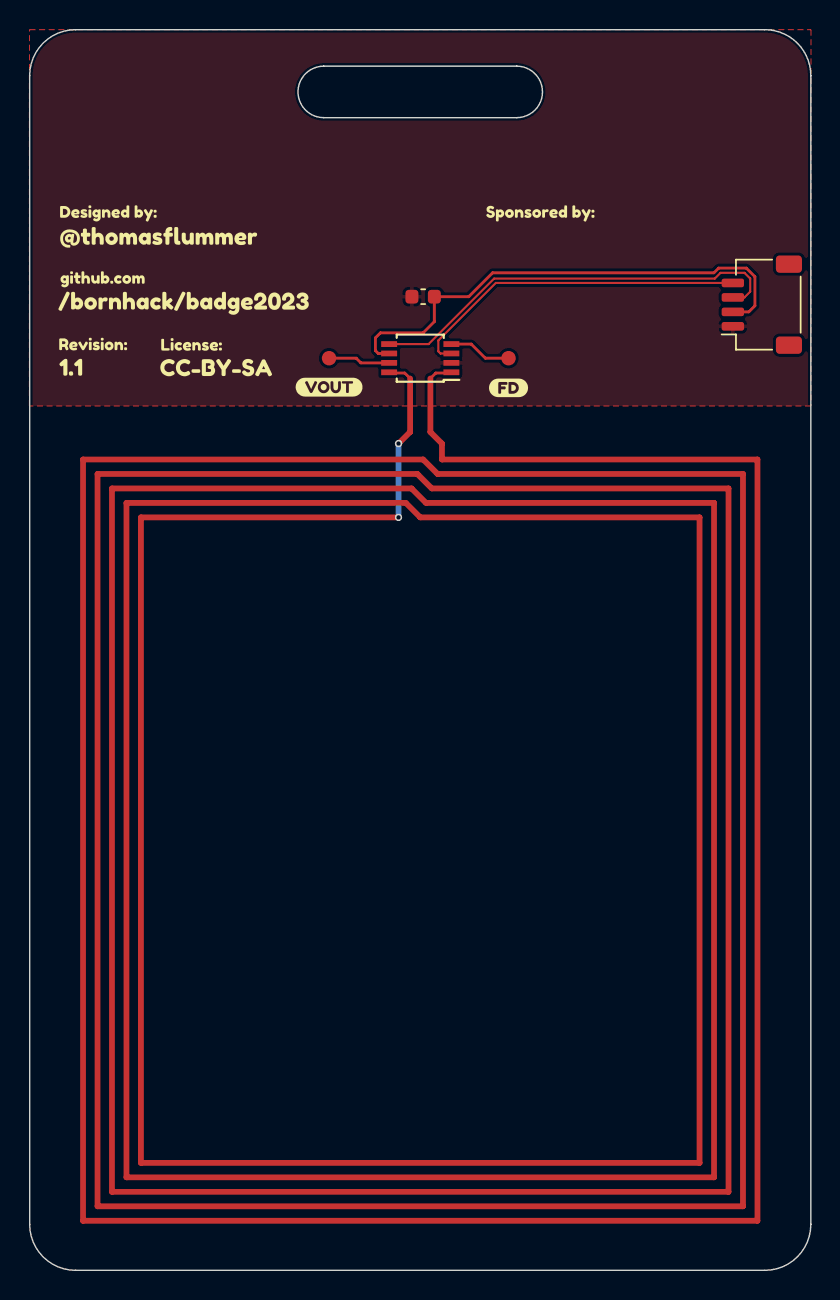
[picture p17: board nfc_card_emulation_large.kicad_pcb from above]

Board: 2 copper layers, 54.0 x 85.7 mm, 16 parts (0 on the bottom side), 7 nets.

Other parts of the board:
kibuzzard-645C11AA: G***; kibuzzard-645C11AA
kibuzzard-645C104C: G***; kibuzzard-645C104C
kibuzzard-645C107E: G***; kibuzzard-645C107E
kibuzzard-645C118B: G***; kibuzzard-645C118B
kibuzzard-645C1150: G***; kibuzzard-645C1150
kibuzzard-647C9608: G***; kibuzzard-647C9608
kibuzzard-649468CC: G***; kibuzzard-649468CC
kibuzzard-649468E2: G***; kibuzzard-649468E2
kibuzzard-649469D3: G***; kibuzzard-649469D3
kibuzzard-64946969: G***; kibuzzard-64946969
kibuzzard-64946977: G***; kibuzzard-64946977

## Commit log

2023-06-23 Added front artwork to nfc_card_emulation_large
    Also created BOM and pos files
    [nfc_card_emulation_large-B_Cu.gbl, nfc_card_emulation_large-B_Mask.gbs, nfc_card_emulation_large-B_Paste.gbp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]
2023-06-23 Added front artwork to nfc_reader
    Also
    - Fixed error with missing power to PN7150 radio
    - Added two buttons and two LEDs
    - Moved things around a little
    - Updated BOM and created pos file
    [nfc_reader-B_Cu.gbl, nfc_reader-B_Mask.gbs, nfc_reader-B_Paste.gbp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]
2023-06-23 Added I/O Expander board
    [io_expander-B_Cu.gbl, io_expander-B_Mask.gbs, io_expander-B_Paste.gbp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]
2023-06-25 Added schematics as PDF files
2023-08-01 Added link to circuitpython branch
2023-08-05 Added circuitpython firmware.uf2 binary for restore
2023-10-15 Fixed I2C I/O Expander design
    - Added pullup resistors on buttons
    - Changed to 3 pin solder jumpers, to allow address pins to be tied to either VCC or GND
    [io_expander-B_Cu.gbl, io_expander-B_Mask.gbs, io_expander-B_Paste.gbp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]
2023-10-15 Updated Interactive BOM for I2C I/O Expander
    [io_expander.kicad_pcb]
